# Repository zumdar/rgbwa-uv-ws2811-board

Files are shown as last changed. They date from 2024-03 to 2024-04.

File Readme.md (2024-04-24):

# RGBWA+UV LED with 2x WS2811 chipss

fun collab w/ eddie farr!

Eddie made CamperLightsSMD and I modified and made the dome_rgbwauv_pcb file

# dome_rgbwauv_pcb

For the LED dome / barnacle project
Rev. A:
- features mosfet circuit so more current can go to the led
- jumper so you can toggle between the mosfet circuit and just using the ws2811 output
- 2x holes (H1 & H2) should line up so you can screw this pcb into the plastic dome and use it as base
- JST connector on back so you can connect data and power easily
- 4 other holes to mount standoffs so you can mount this on a substrate?
- hole in middle of LED for heatsink

# similar projects
Neopixel XL - https://github.com/palsayantan/Neopixel-XL

## REV. A renders
front:
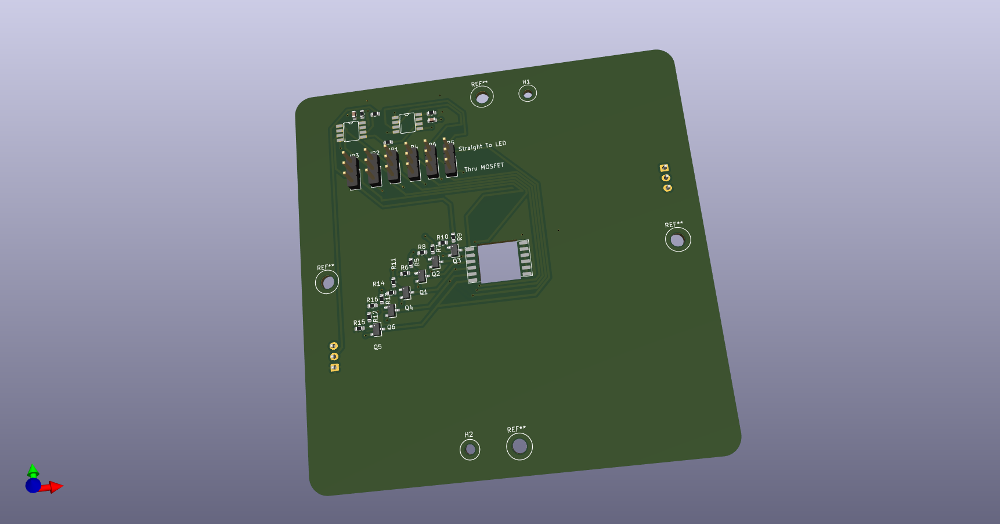
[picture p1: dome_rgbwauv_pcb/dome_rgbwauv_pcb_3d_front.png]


back:
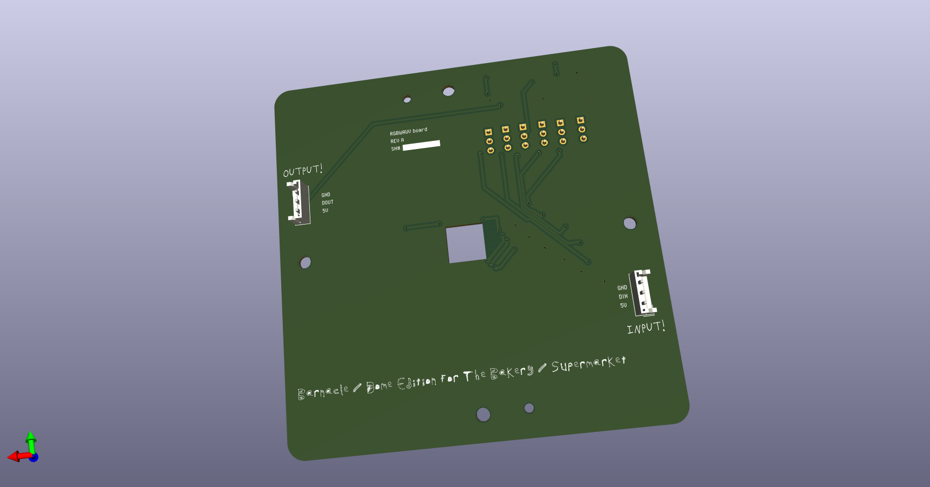
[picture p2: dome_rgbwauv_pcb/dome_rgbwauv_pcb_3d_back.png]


[Rev A Layout PDF](dome_rgbwauv_pcb/dome_rgbwauv_pcb_LAYOUT.pdf)
## Schematic 
[Schematic](dome_rgbwauv_pcb/dome_rgbwauv_Schematic.pdf)

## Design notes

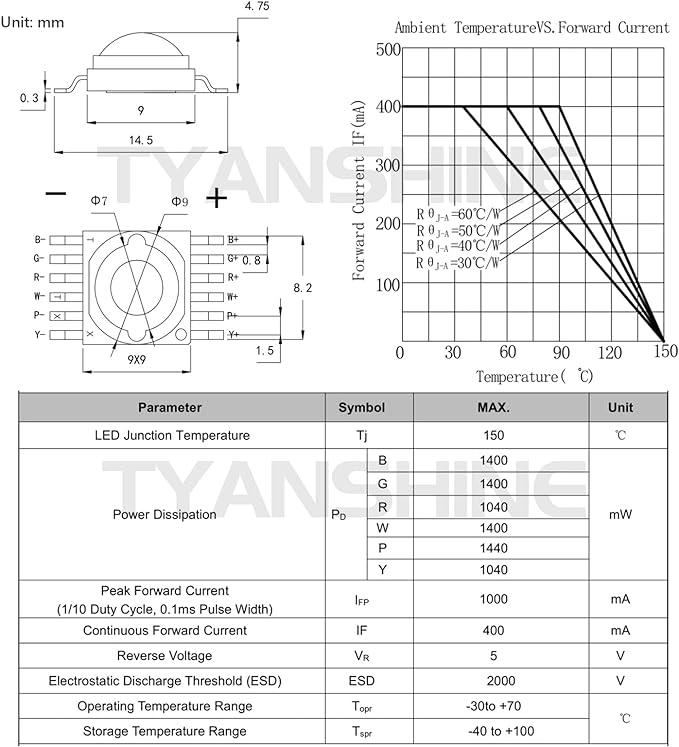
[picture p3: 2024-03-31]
Datasheets/led_data_sheet1.jpg

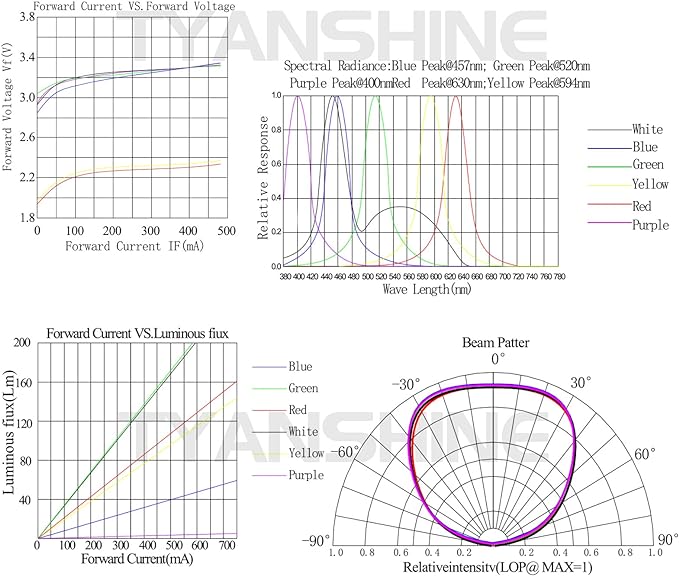
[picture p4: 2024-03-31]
Datasheets/led_data_sheet2.jpg

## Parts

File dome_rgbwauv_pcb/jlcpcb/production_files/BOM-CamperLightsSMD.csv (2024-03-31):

Comment | Designator | Footprint | LCSC
0.1 uf | C1,C2 | C_0603_1608Metric | C14663
100 | R2,R4 | R_0603_1608Metric | C22775
33 | R1,R3 | R_0603_1608Metric | C23140
WS2811 | IC1,IC2 | SO08-SKINNYPADS | C2920043
RGBAW+UV | U1 | RGBWA+UV
MountingHole | H2 | MountingHole_2.2mm_M2
MountingHole | H1 | MountingHole_2.2mm_M2
Conn_01x03_Male | J2 | JST_EH_B3B-EH-A_1x03_P2.50mm_Vertical
Conn_01x03_Male | J1 | JST_EH_B3B-EH-A_1x03_P2.50mm_Vertical

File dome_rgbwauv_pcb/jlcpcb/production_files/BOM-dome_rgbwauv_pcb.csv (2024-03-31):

Comment | Designator | Footprint | LCSC
0.1 uf | C1,C2 | C_0603_1608Metric | C14663
AO3400A | Q1,Q2,Q3,Q4,Q5,Q6 | SOT-23-3_L2.9-W1.6-P1.90-LS2.8-BR | C20917
1k | R11,R12,R13,R5,R7,R9 | R_0603_1608Metric | C21190
100 | R2,R4 | R_0603_1608Metric | C22775
33 | R1,R3 | R_0603_1608Metric | C23140
10k | R10,R14,R15,R16,R6,R8 | R_0603_1608Metric | C25804
WS2811 | IC1,IC2 | SO08-SKINNYPADS | C2920043
RGBAW+UV | U1 | RGBWA+UV
Board_to_dome | H2 | MountingHole_2.2mm_M2
Board_to_dome | H1 | MountingHole_2.2mm_M2
3PinJSTOutput | J2 | JST_EH_B3B-EH-A_1x03_P2.50mm_Vertical
3PinJSTInput | J1 | JST_EH_B3B-EH-A_1x03_P2.50mm_Vertical
Jumper | JP1 | PinHeader_1x03_P2.54mm_Vertical
Jumper | JP2 | PinHeader_1x03_P2.54mm_Vertical
Jumper | JP5 | PinHeader_1x03_P2.54mm_Vertical
Jumper | JP3 | PinHeader_1x03_P2.54mm_Vertical
Jumper | JP4 | PinHeader_1x03_P2.54mm_Vertical
Jumper | JP6 | PinHeader_1x03_P2.54mm_Vertical

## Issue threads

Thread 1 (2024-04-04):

improvement of REV.A pcb run

zumdar, 2024-04-04:
Potential upgrades or problems with board
- 12V input might be better then 5V
   - would need a 12 to 5 regulator for the chip
- heat sink the whole board?

zumdar, 2024-04-10:
- mosfet needs to be pulled high .? when not actively driven...

zumdar, 2024-05-09:
- it is being pulled high when not driven. so need to get multimeter or scope out and read voltage on it.

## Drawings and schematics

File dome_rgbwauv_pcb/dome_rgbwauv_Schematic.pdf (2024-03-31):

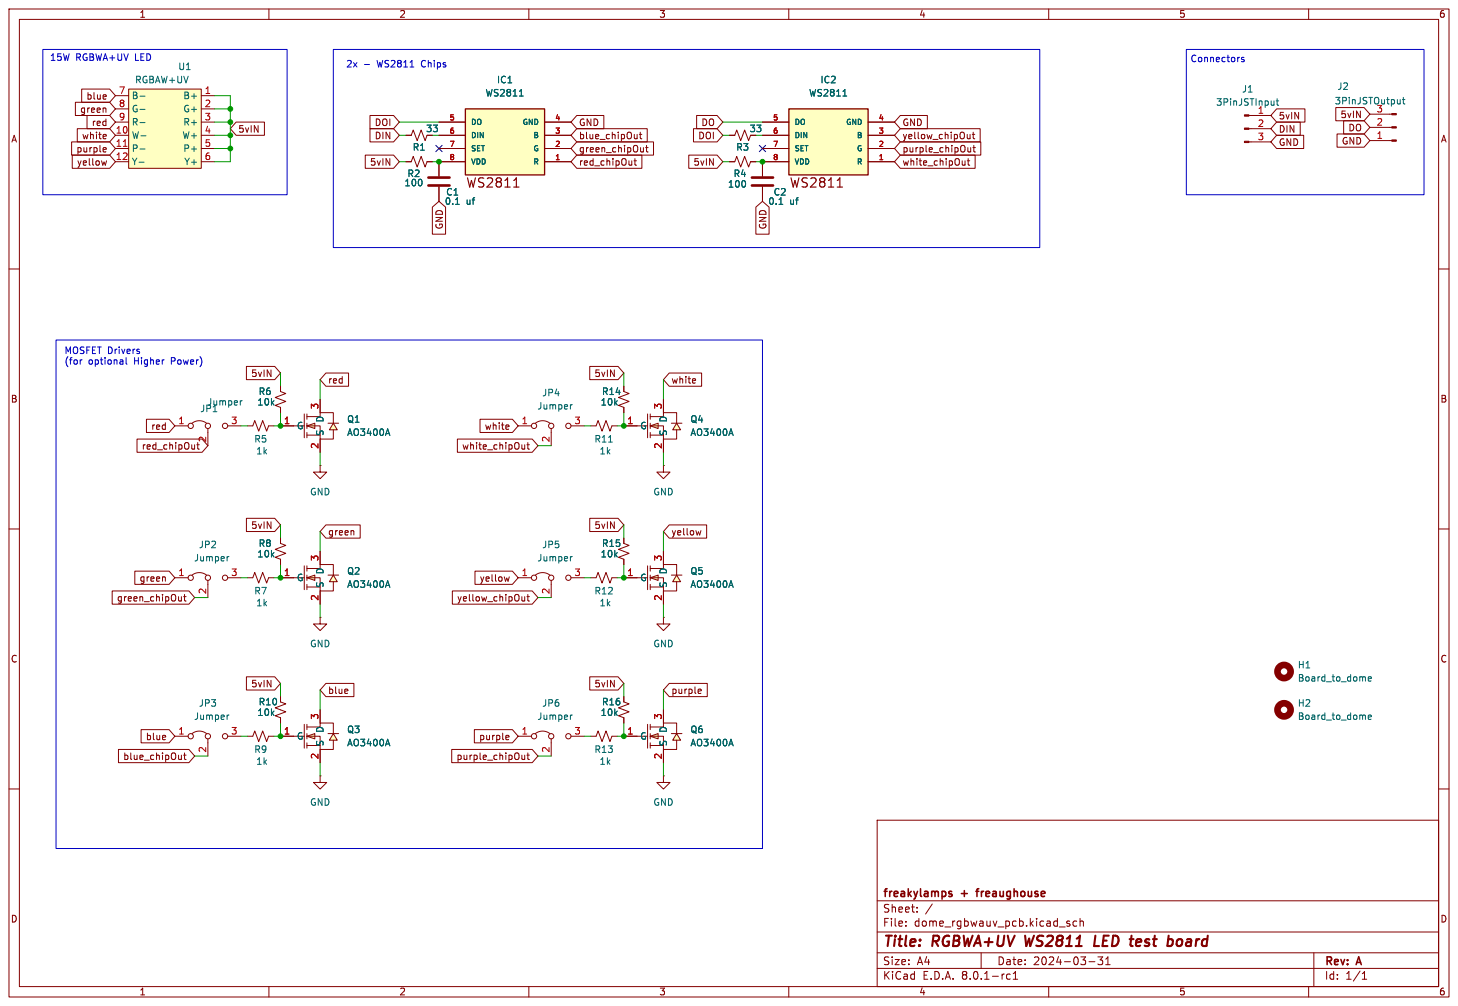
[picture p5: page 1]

Id: 1/1 Title: RGBWA+UV WS2811 LED test board

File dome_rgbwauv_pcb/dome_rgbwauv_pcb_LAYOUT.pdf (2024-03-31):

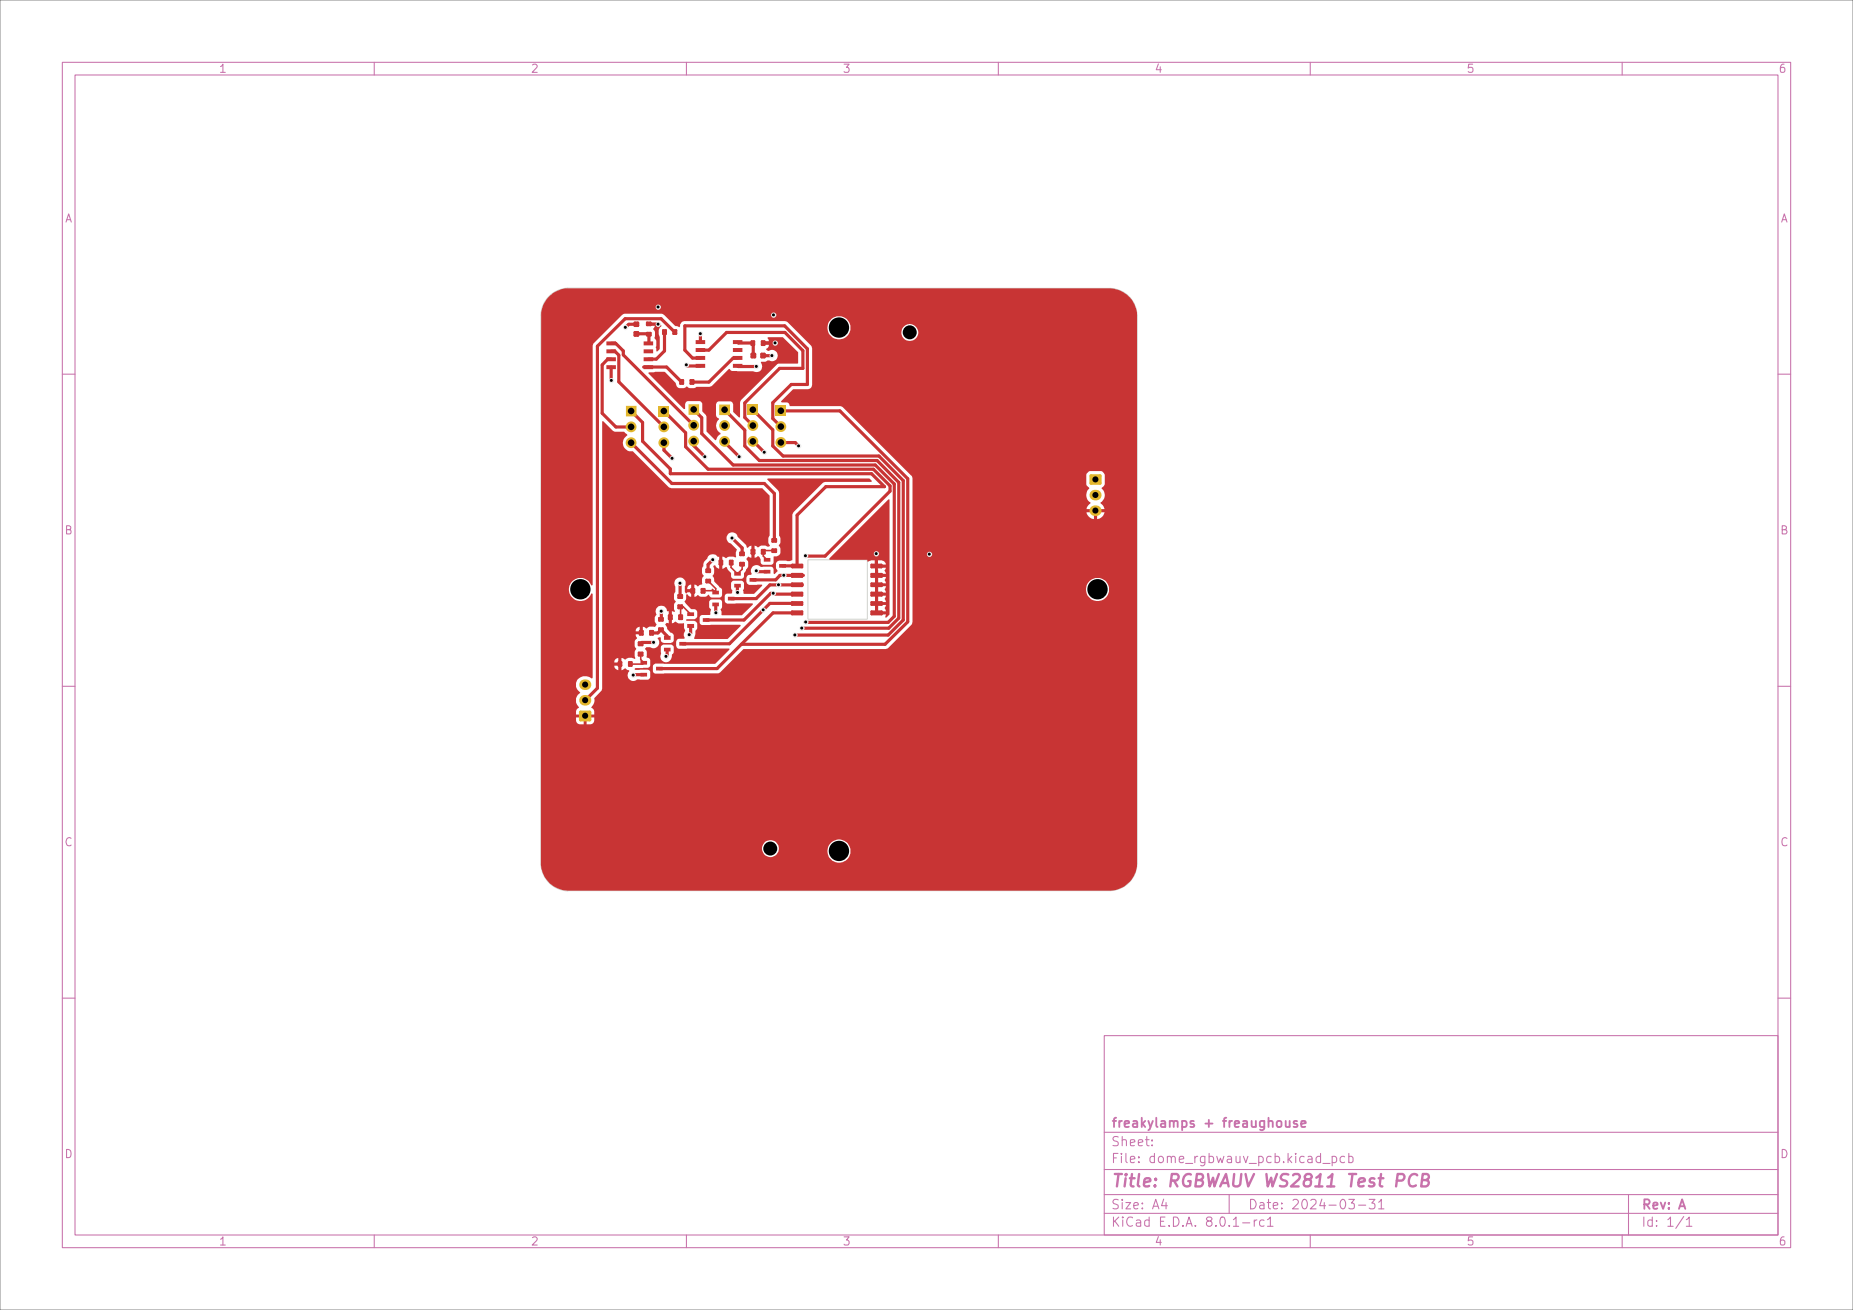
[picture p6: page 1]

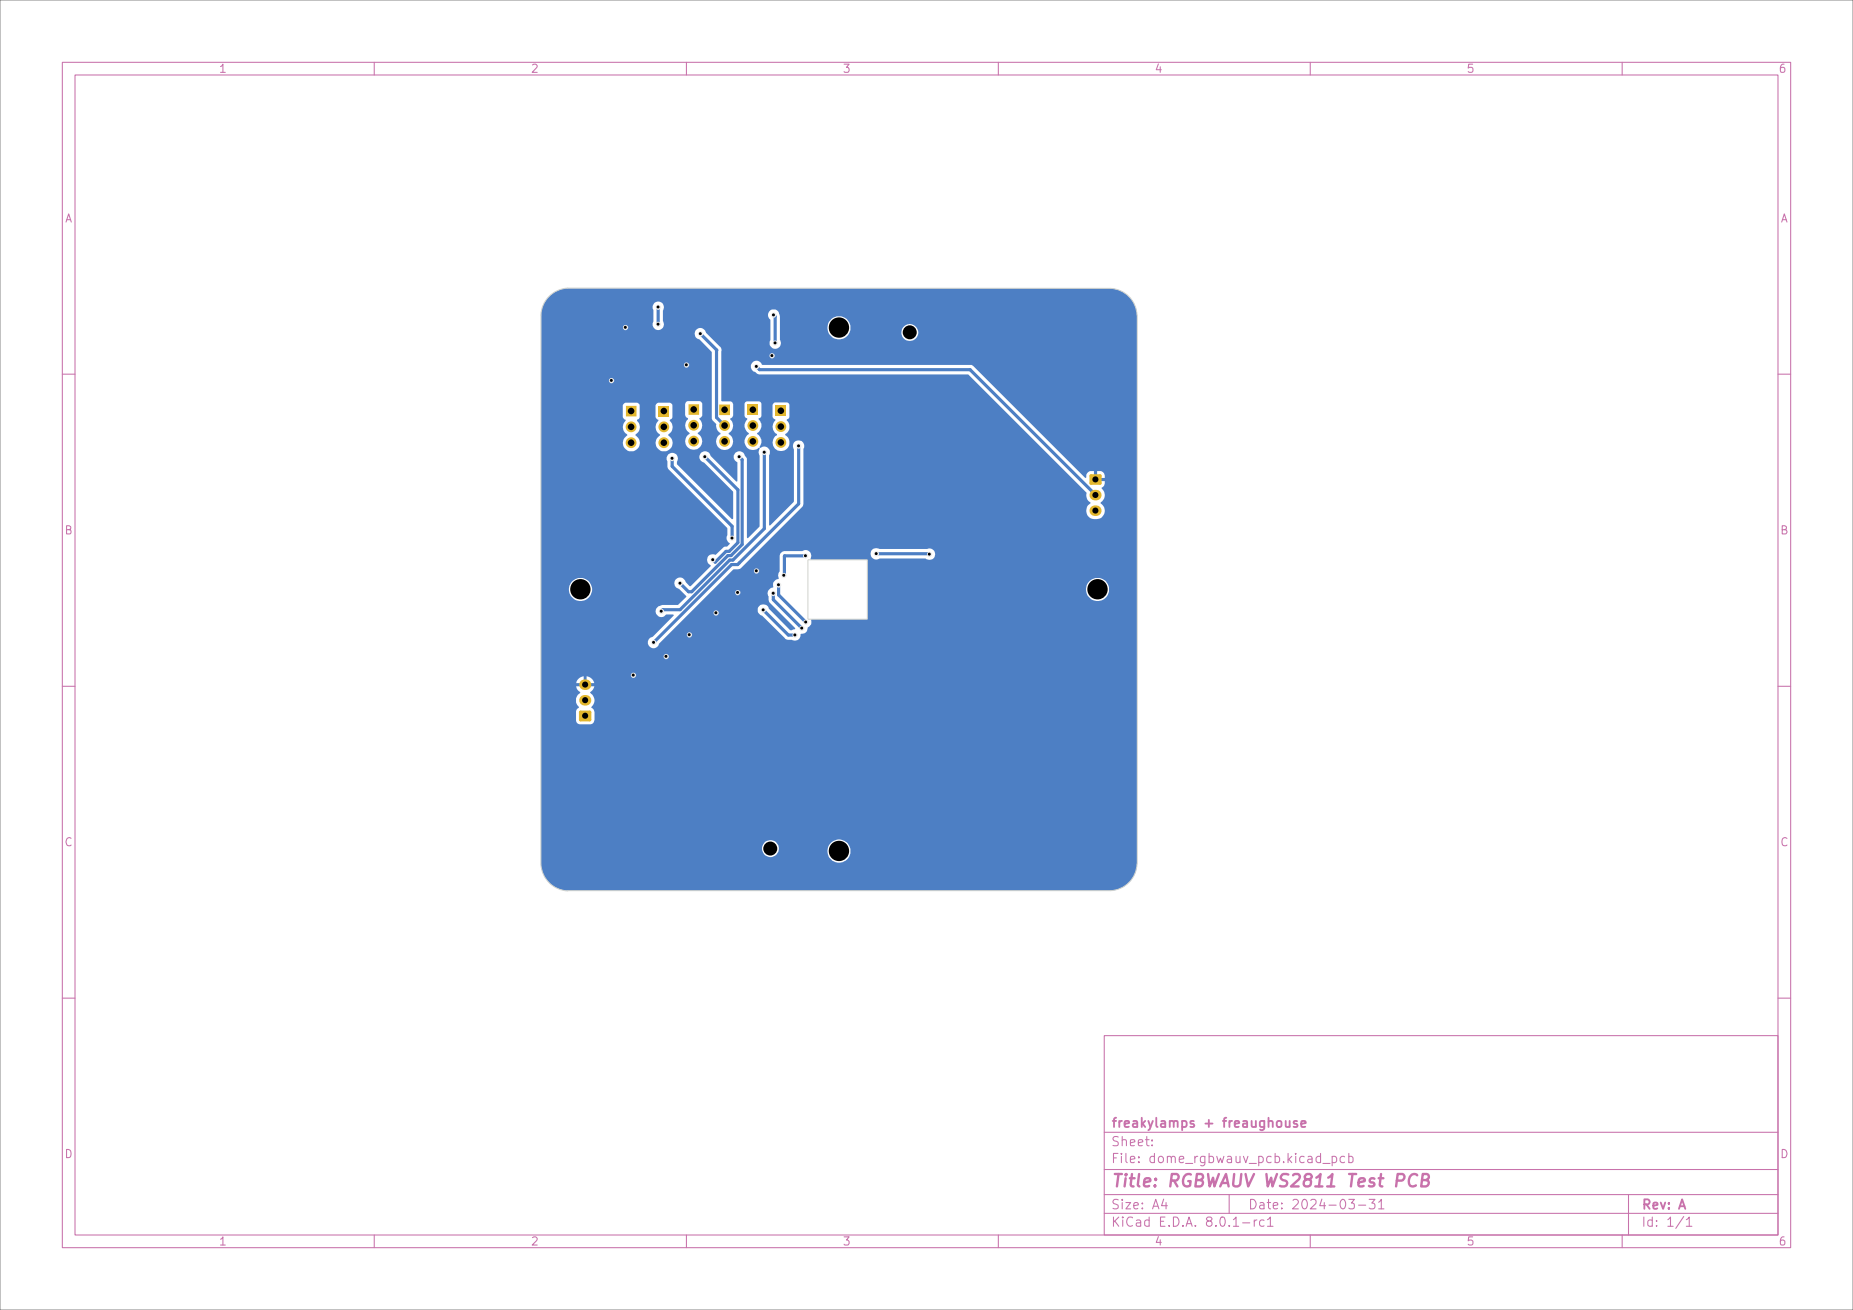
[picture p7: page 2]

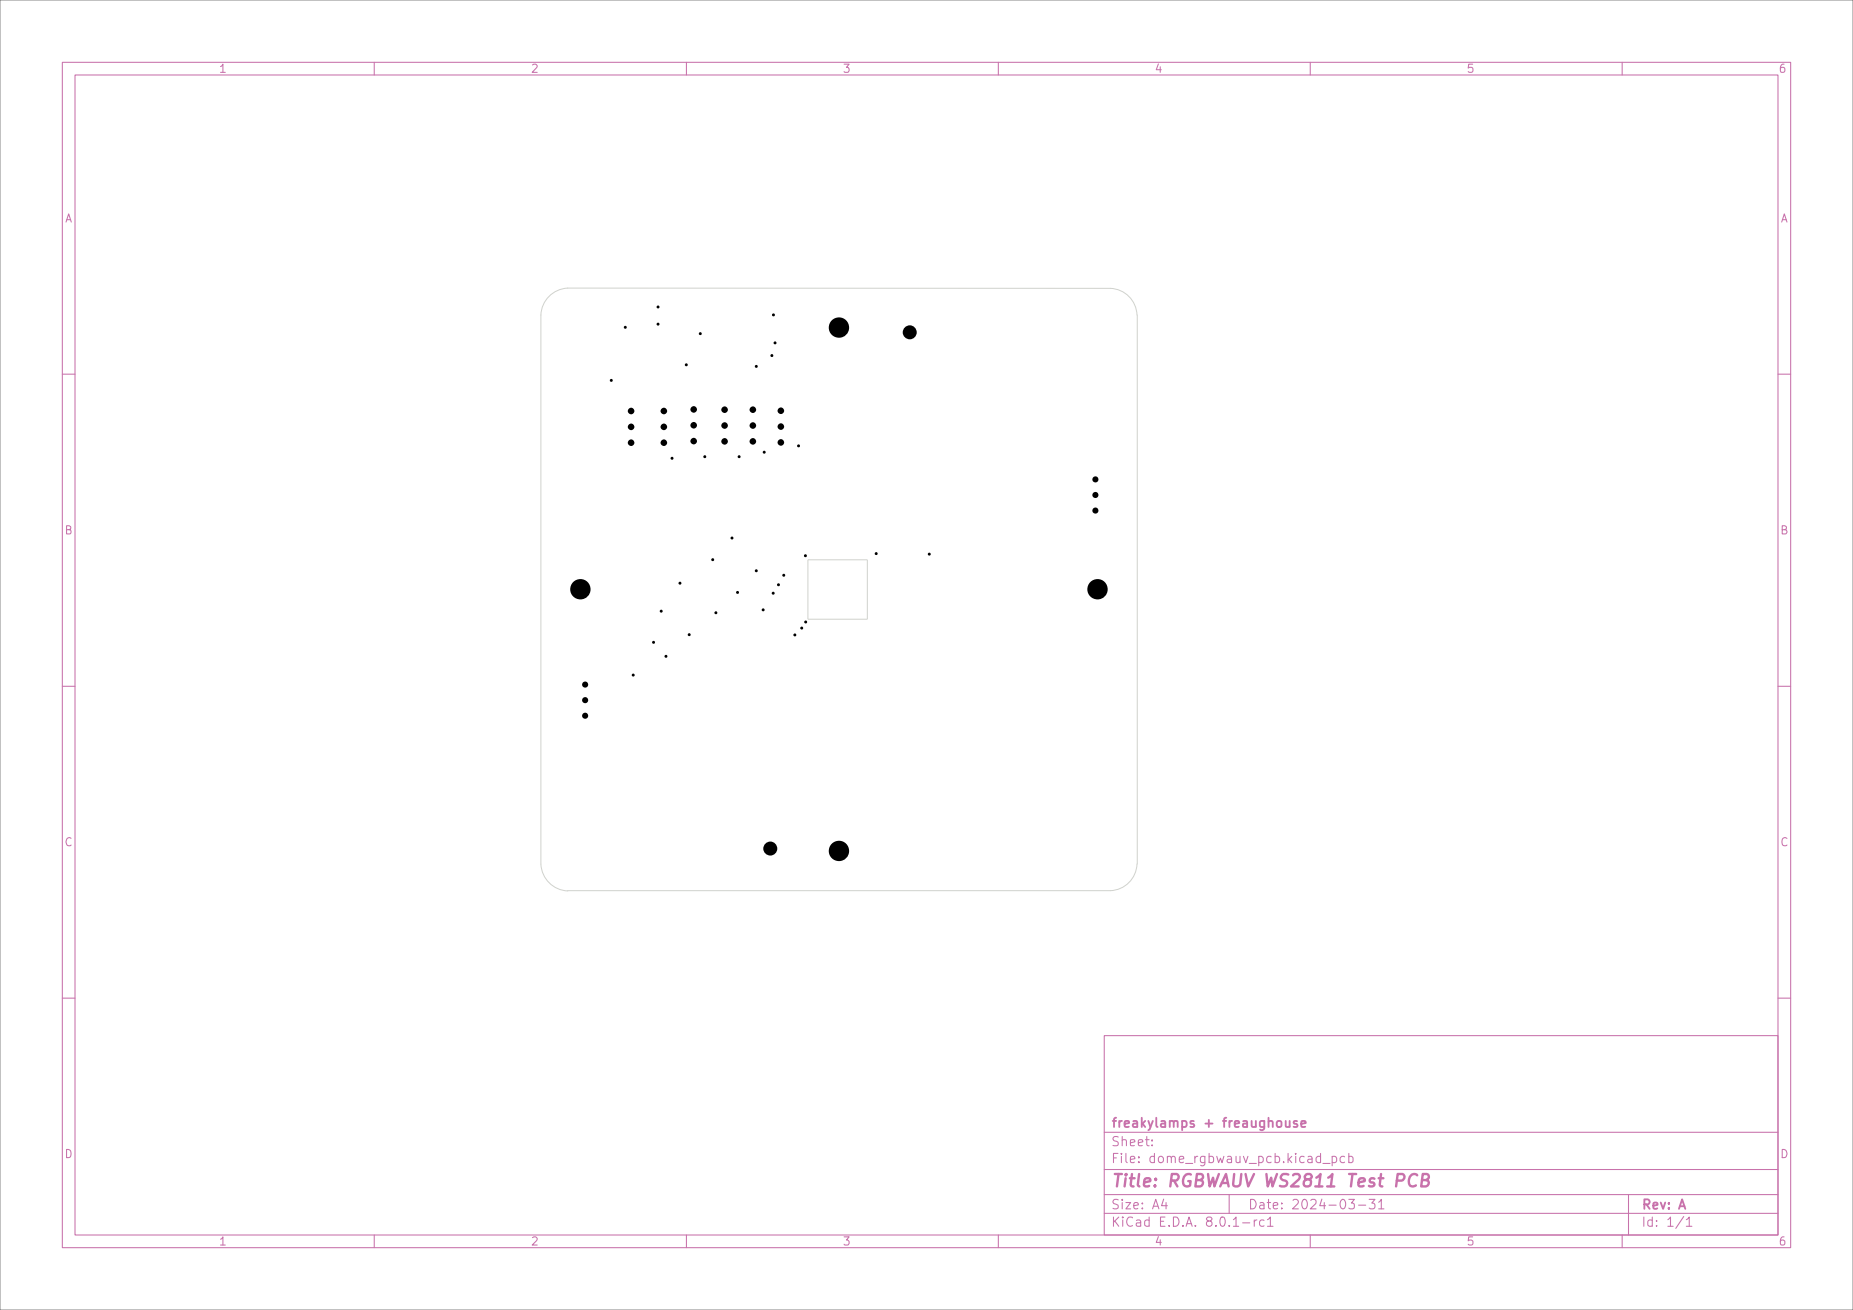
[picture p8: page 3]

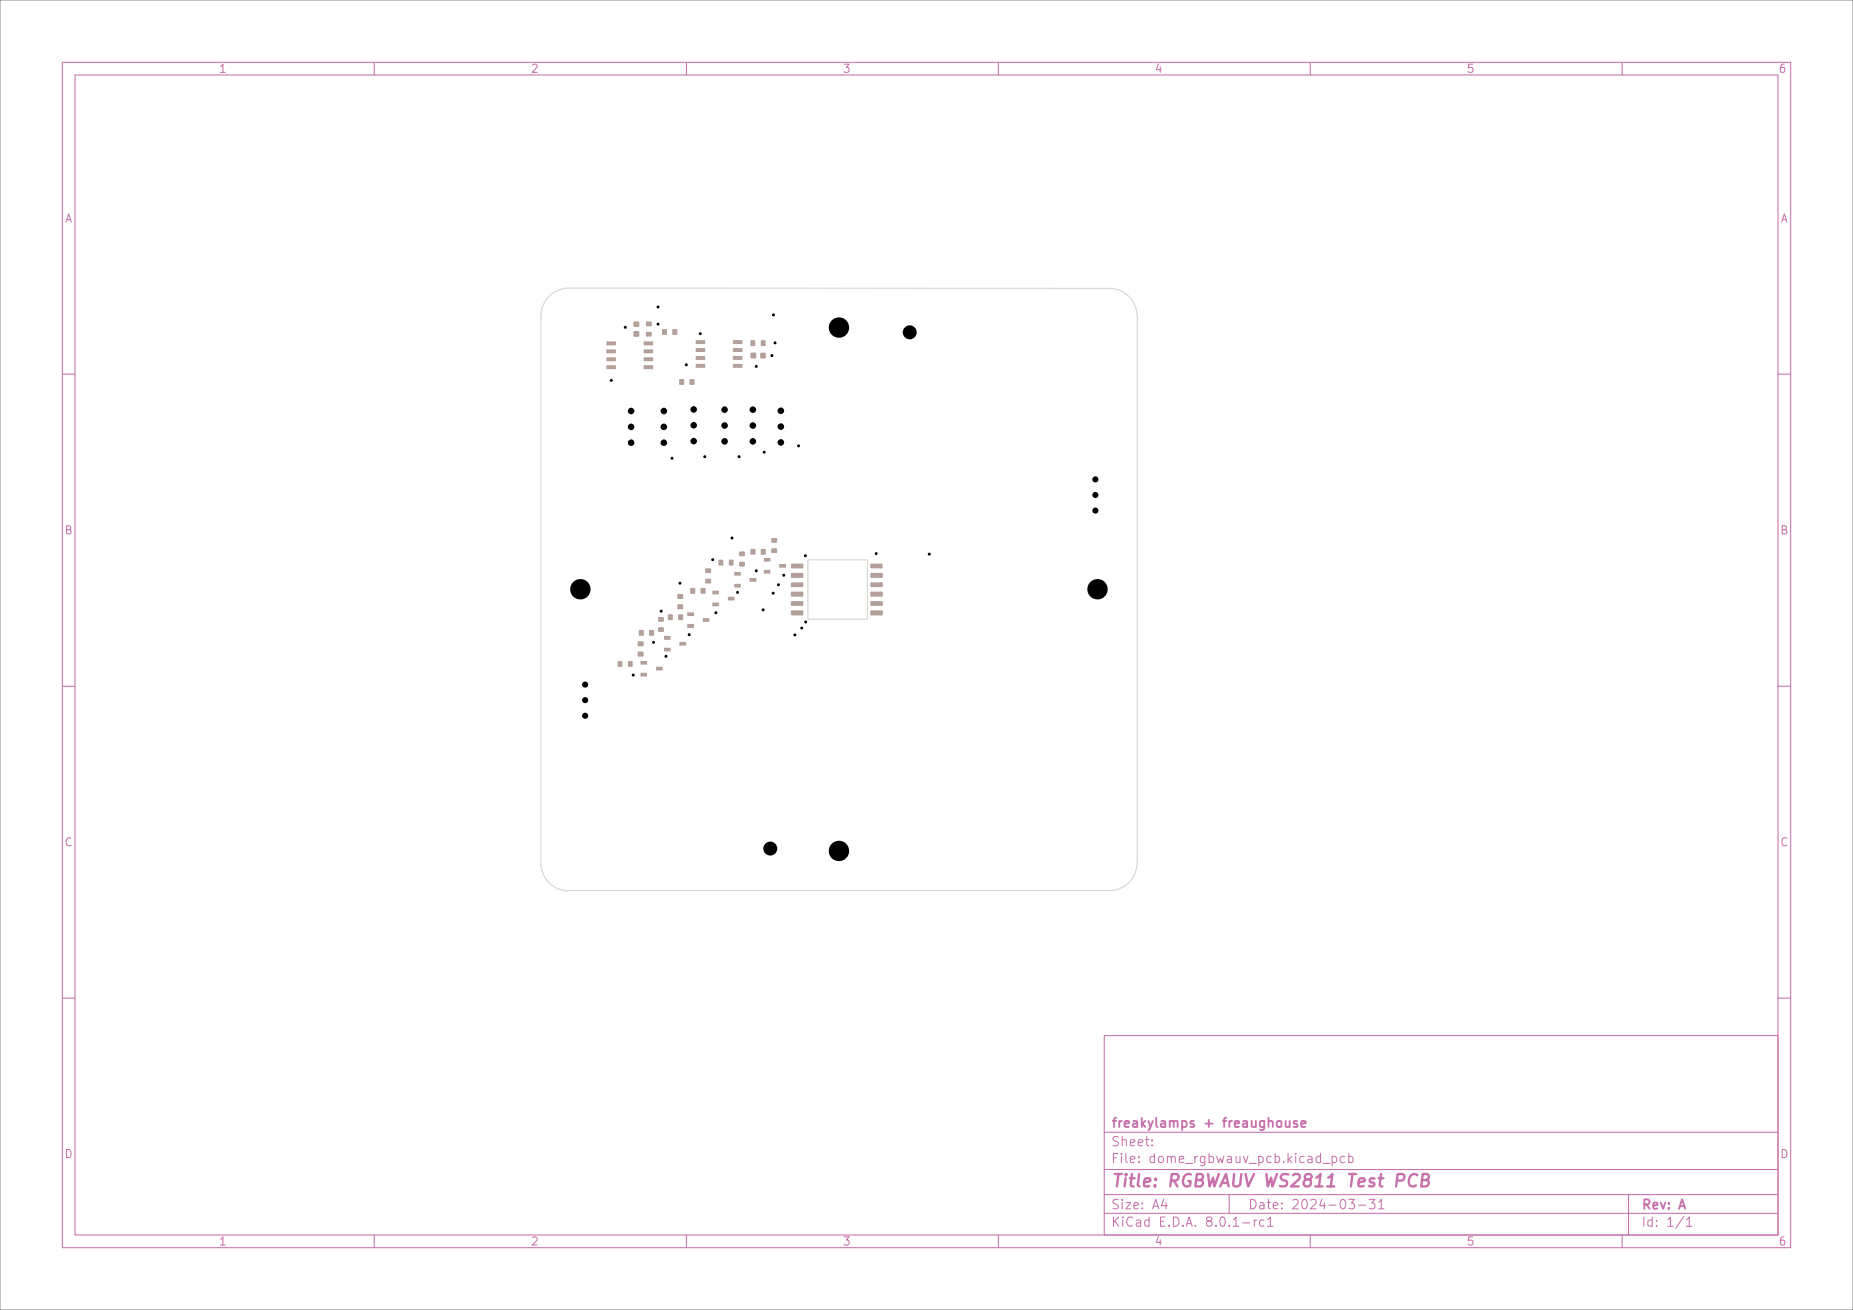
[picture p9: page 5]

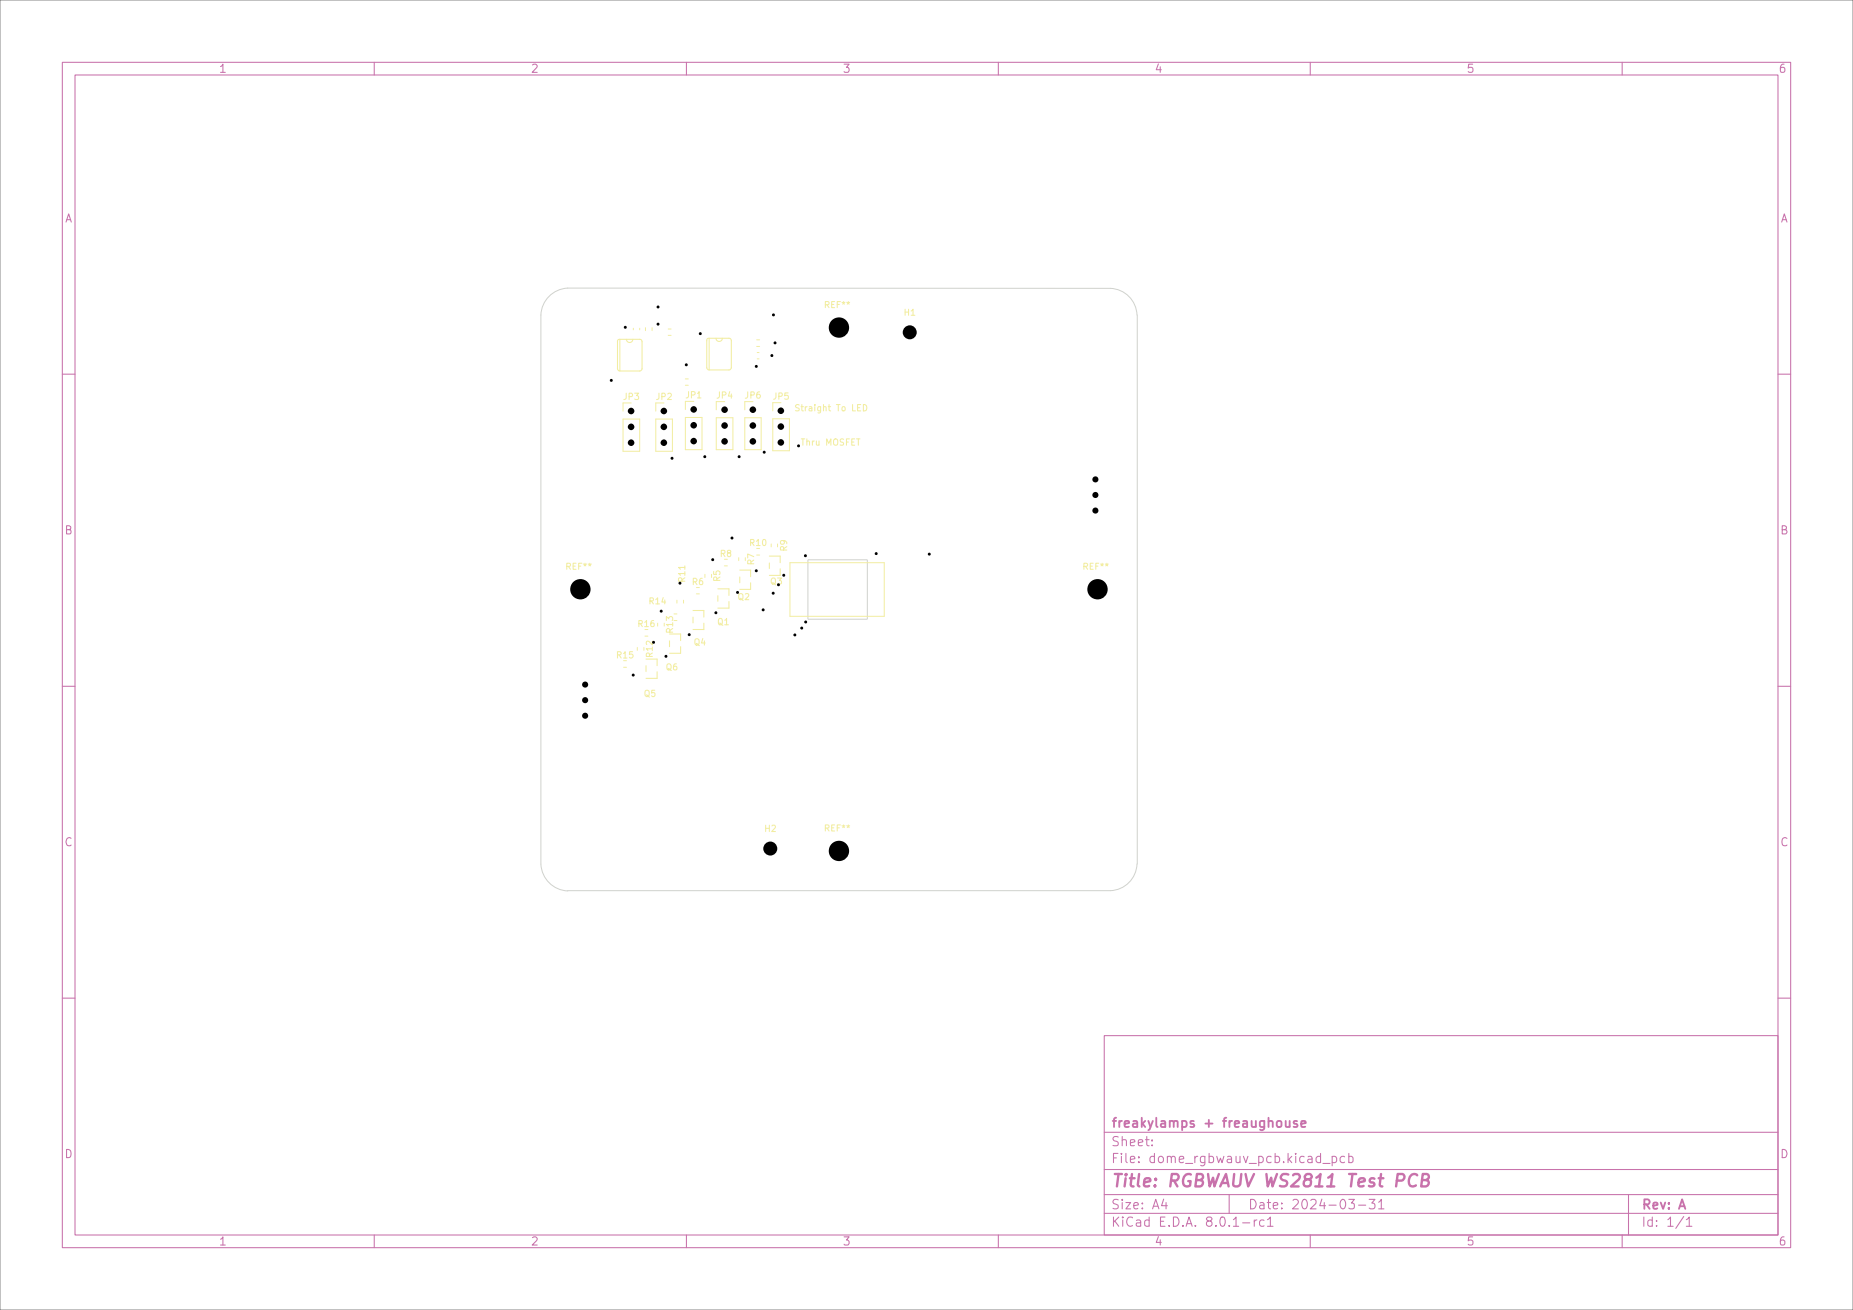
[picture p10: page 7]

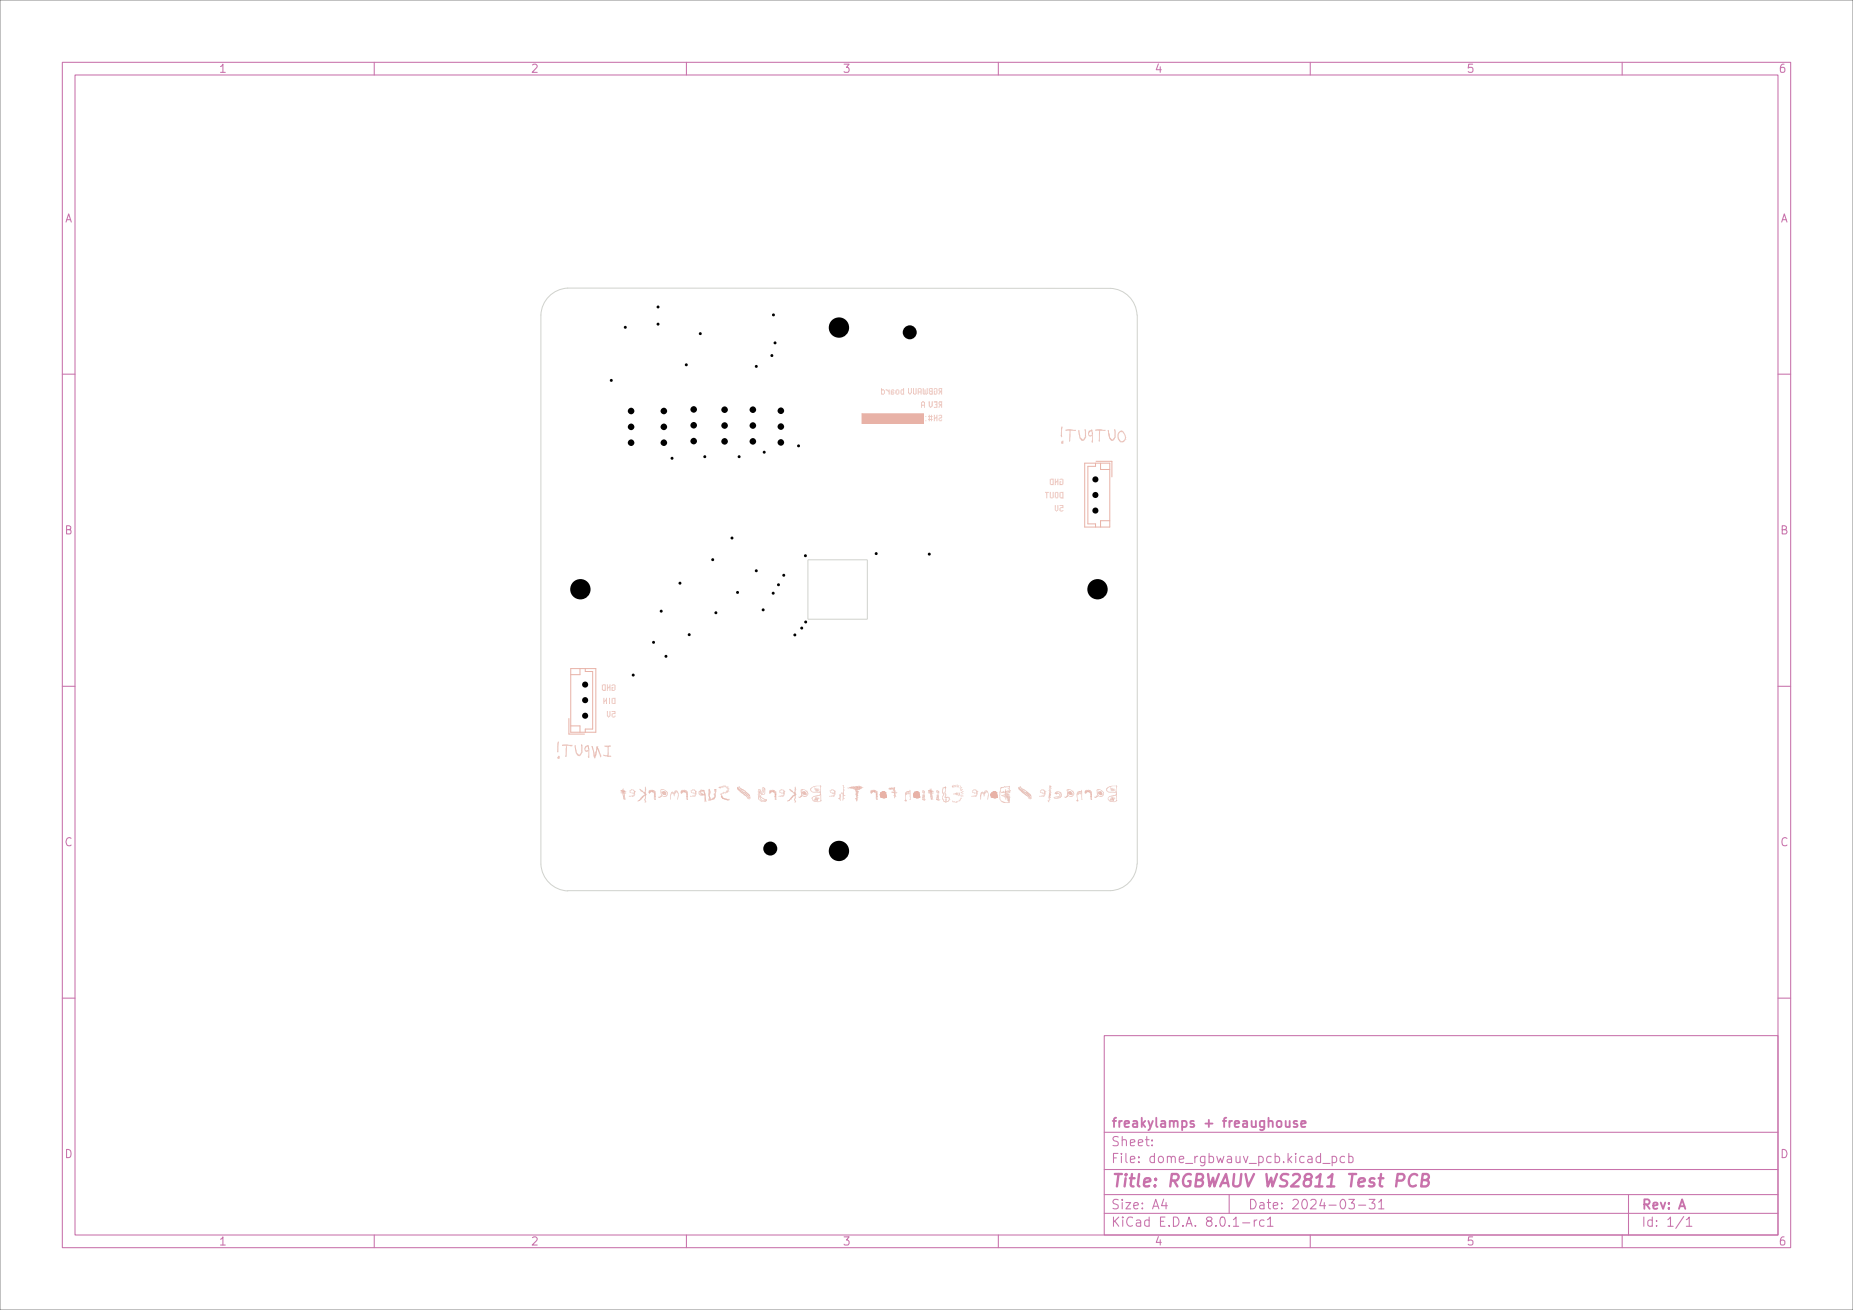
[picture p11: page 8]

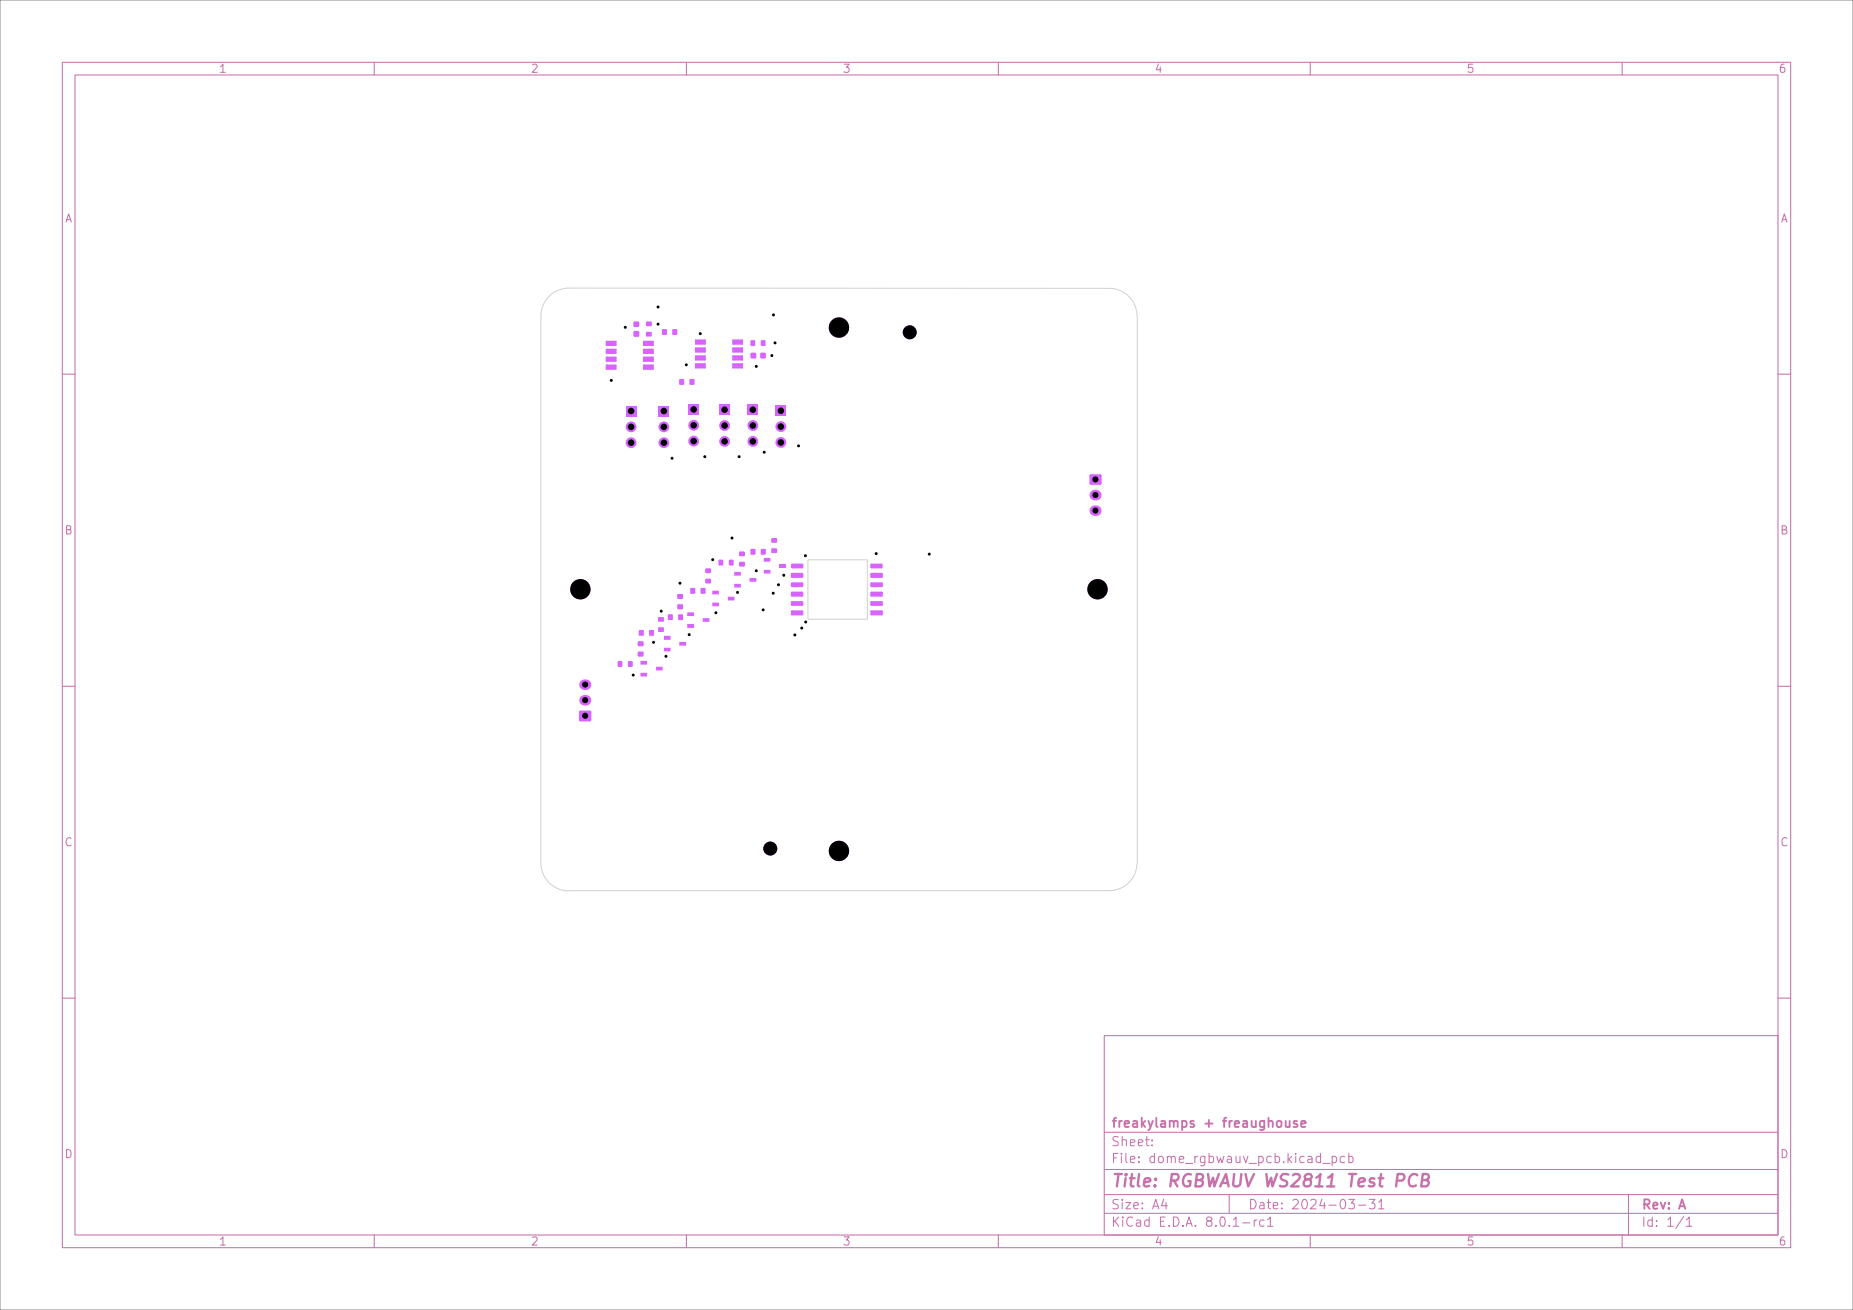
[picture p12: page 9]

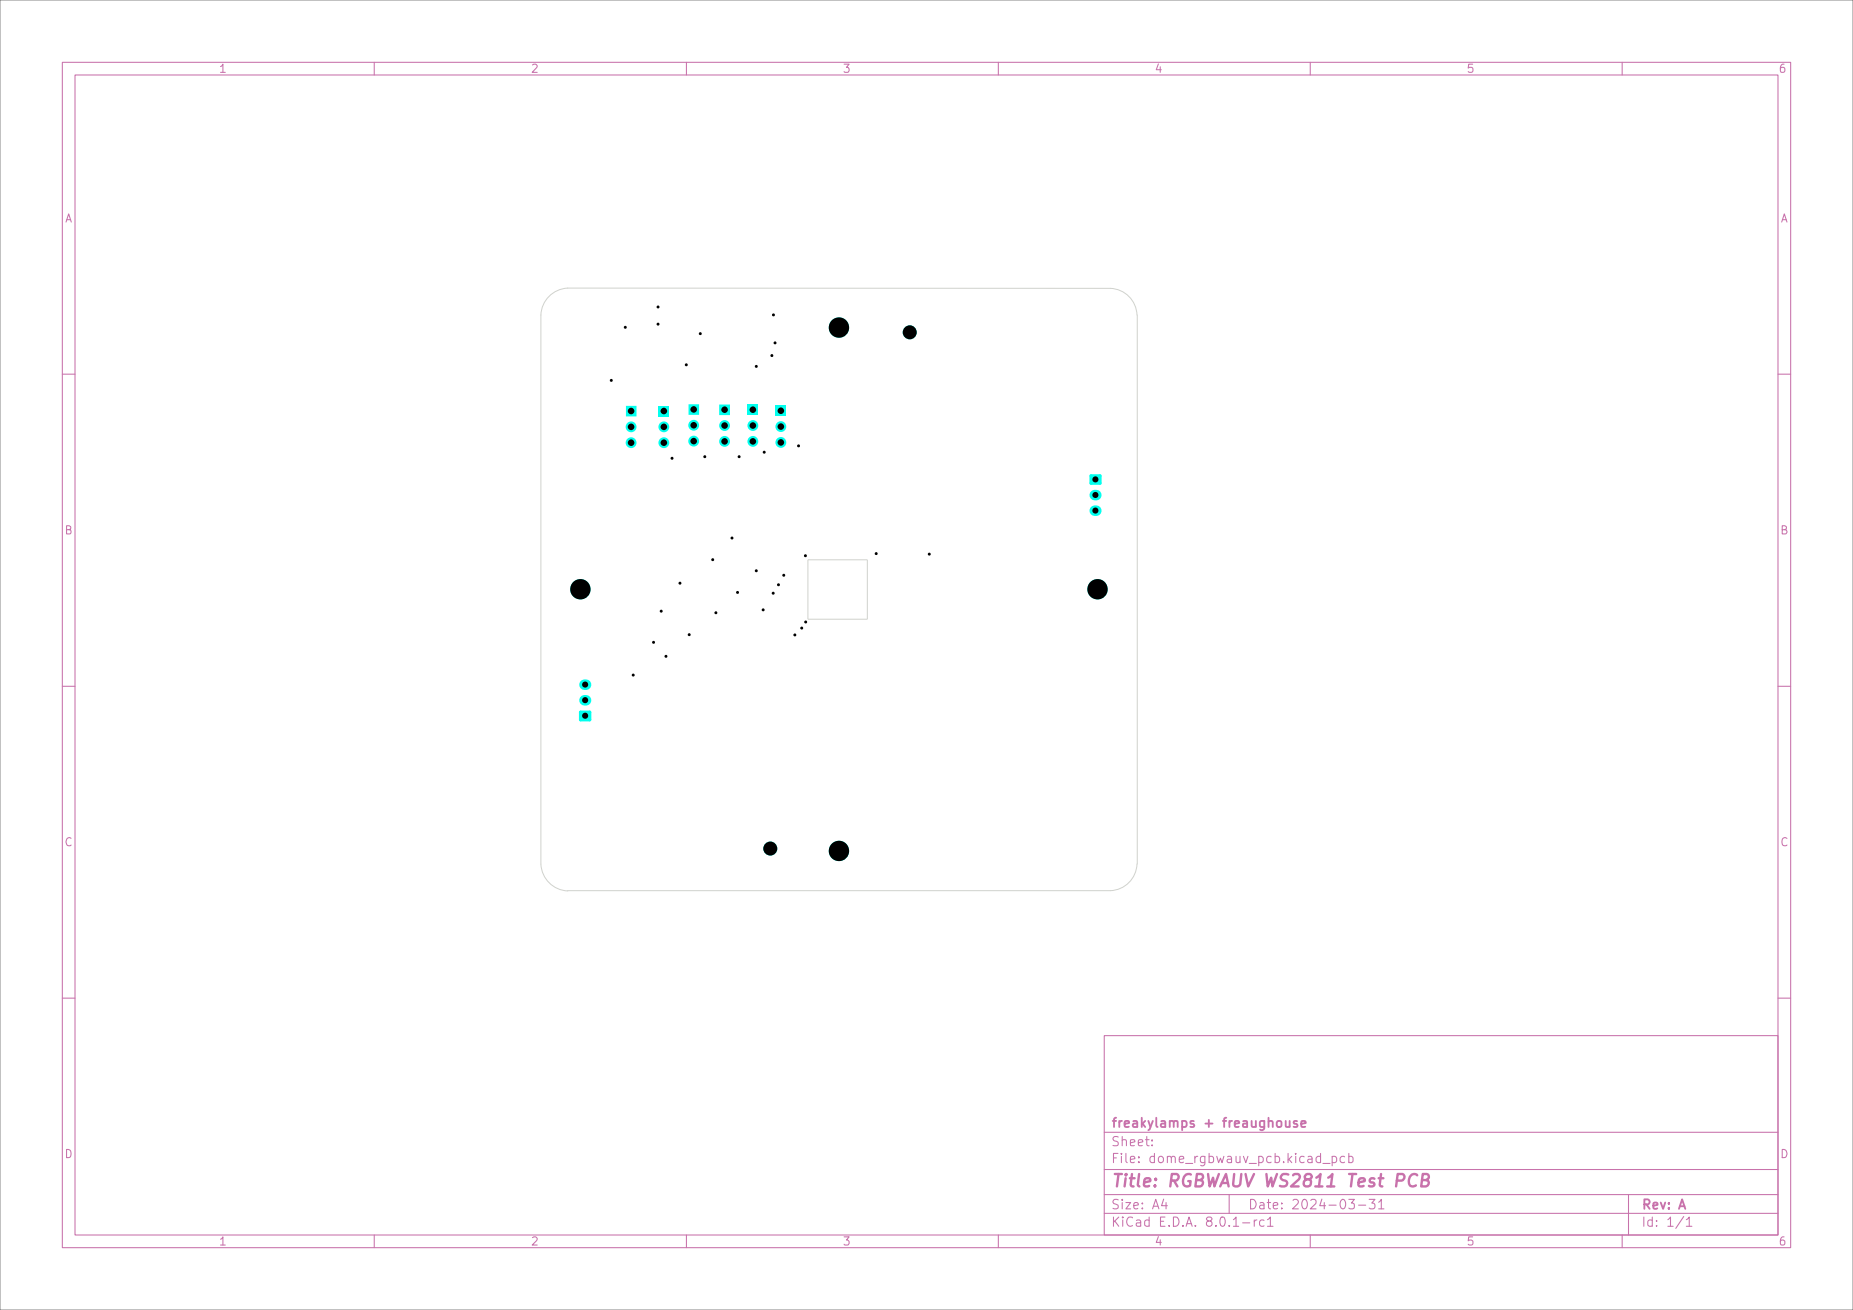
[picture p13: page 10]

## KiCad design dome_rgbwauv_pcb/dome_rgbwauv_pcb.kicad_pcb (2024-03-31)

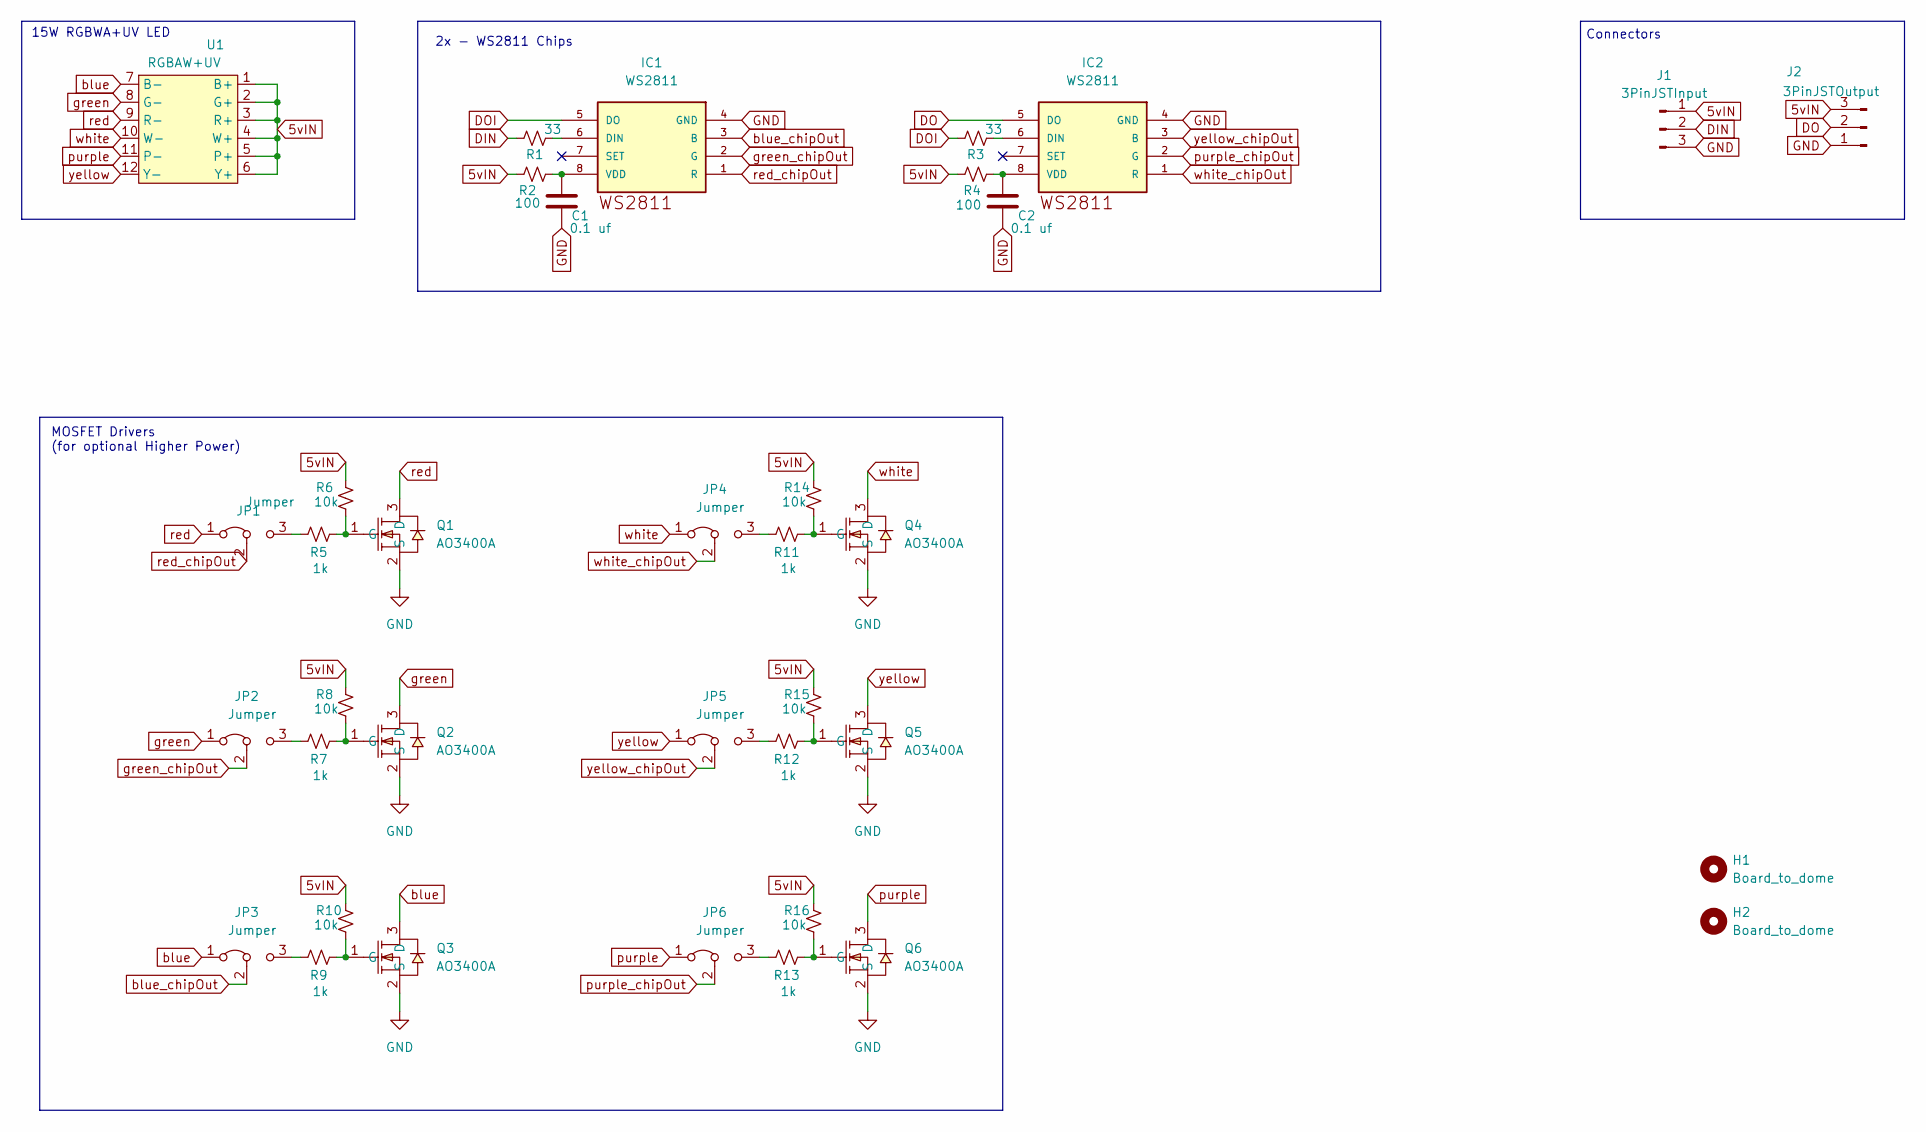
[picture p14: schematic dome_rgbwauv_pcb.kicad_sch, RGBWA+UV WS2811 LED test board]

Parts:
C1, C2: 0.1 uf; C_0603_1608Metric
H1, H2: Board_to_dome; MountingHole_2.2mm_M2
IC1, IC2: WS2811; SO08-SKINNYPADS
J1: 3PinJSTInput; JST_EH_B3B-EH-A_1x03_P2.50mm_Vertical
J2: 3PinJSTOutput; JST_EH_B3B-EH-A_1x03_P2.50mm_Vertical
JP1, JP2, JP3, JP4, JP5, JP6: Jumper; PinHeader_1x03_P2.54mm_Vertical
Q1, Q2, Q3, Q4, Q5, Q6: AO3400A; SOT-23-3_L2.9-W1.6-P1.90-LS2.8-BR; LCSC Part C20917
R1, R3: 33; R_0603_1608Metric
R2, R4: 100; R_0603_1608Metric
R5, R7, R9, R11, R12, R13: 1k; R_0603_1608Metric
R6, R8, R10, R14, R15, R16: 10k; R_0603_1608Metric
U1: RGBAW+UV; RGBWA+UV

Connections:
5vIN: J1.1, J2.3, R2.1, R4.1, R6.1, R8.1, R10.1, R14.1, R15.1, R16.1, U1.1 (B+), U1.2 (G+), U1.3 (R+), U1.4 (W+), U1.5 (P+), U1.6 (Y+)
DIN: J1.2, R1.1
DO: IC2.5 (DO), J2.2
DOI: IC1.5 (DO), R3.1
GND: C1.2, C2.2, IC1.4 (GND), IC2.4 (GND), J1.3, J2.1, Q1.2 (S), Q2.2 (S), Q3.2 (S), Q4.2 (S), Q5.2 (S), Q6.2 (S)
unnamed: IC1.6 (DIN), R1.2
unnamed: C1.1, IC1.8 (VDD), R2.2
unnamed: IC2.6 (DIN), R3.2
unnamed: C2.1, IC2.8 (VDD), R4.2
unnamed: JP1.3 (B), R5.1
unnamed: JP2.3 (B), R7.1
unnamed: JP3.3 (B), R9.1
unnamed: JP4.3 (B), R11.1
unnamed: JP5.3 (B), R12.1
unnamed: JP6.3 (B), R13.1
unnamed: Q1.1 (G), R5.2, R6.2
unnamed: Q2.1 (G), R7.2, R8.2
unnamed: Q3.1 (G), R9.2, R10.2
unnamed: Q4.1 (G), R11.2, R14.2
unnamed: Q5.1 (G), R12.2, R15.2
unnamed: Q6.1 (G), R13.2, R16.2
blue: JP3.1 (A), Q3.3 (D), U1.7 (B-)
blue_chipOut: IC1.3 (B), JP3.2 (C)
green: JP2.1 (A), Q2.3 (D), U1.8 (G-)
green_chipOut: IC1.2 (G), JP2.2 (C)
purple: JP6.1 (A), Q6.3 (D), U1.11 (P-)
purple_chipOut: IC2.2 (G), JP6.2 (C)
red: JP1.1 (A), Q1.3 (D), U1.9 (R-)
red_chipOut: IC1.1 (R), JP1.2 (C)
white: JP4.1 (A), Q4.3 (D), U1.10 (W-)
white_chipOut: IC2.1 (R), JP4.2 (C)
yellow: JP5.1 (A), Q5.3 (D), U1.12 (Y-)
yellow_chipOut: IC2.3 (B), JP5.2 (C)

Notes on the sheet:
15W RGBWA+UV LED
Connectors
MOSFET Drivers (for optional Higher Power)
2x - WS2811 Chips

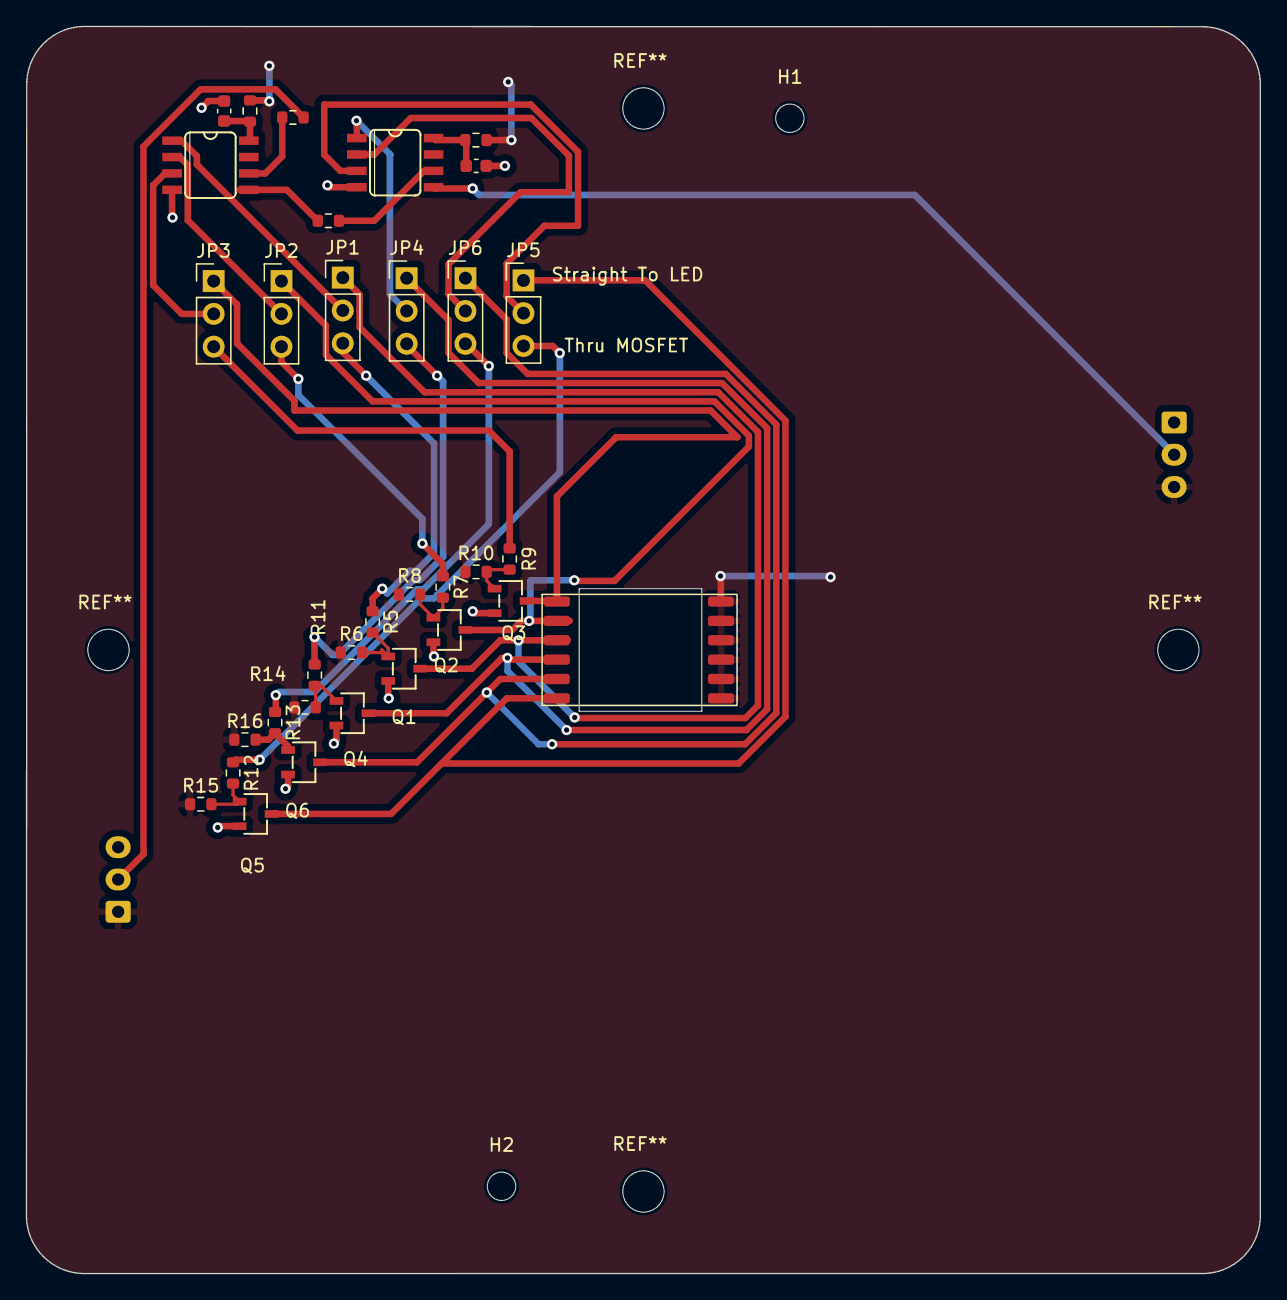
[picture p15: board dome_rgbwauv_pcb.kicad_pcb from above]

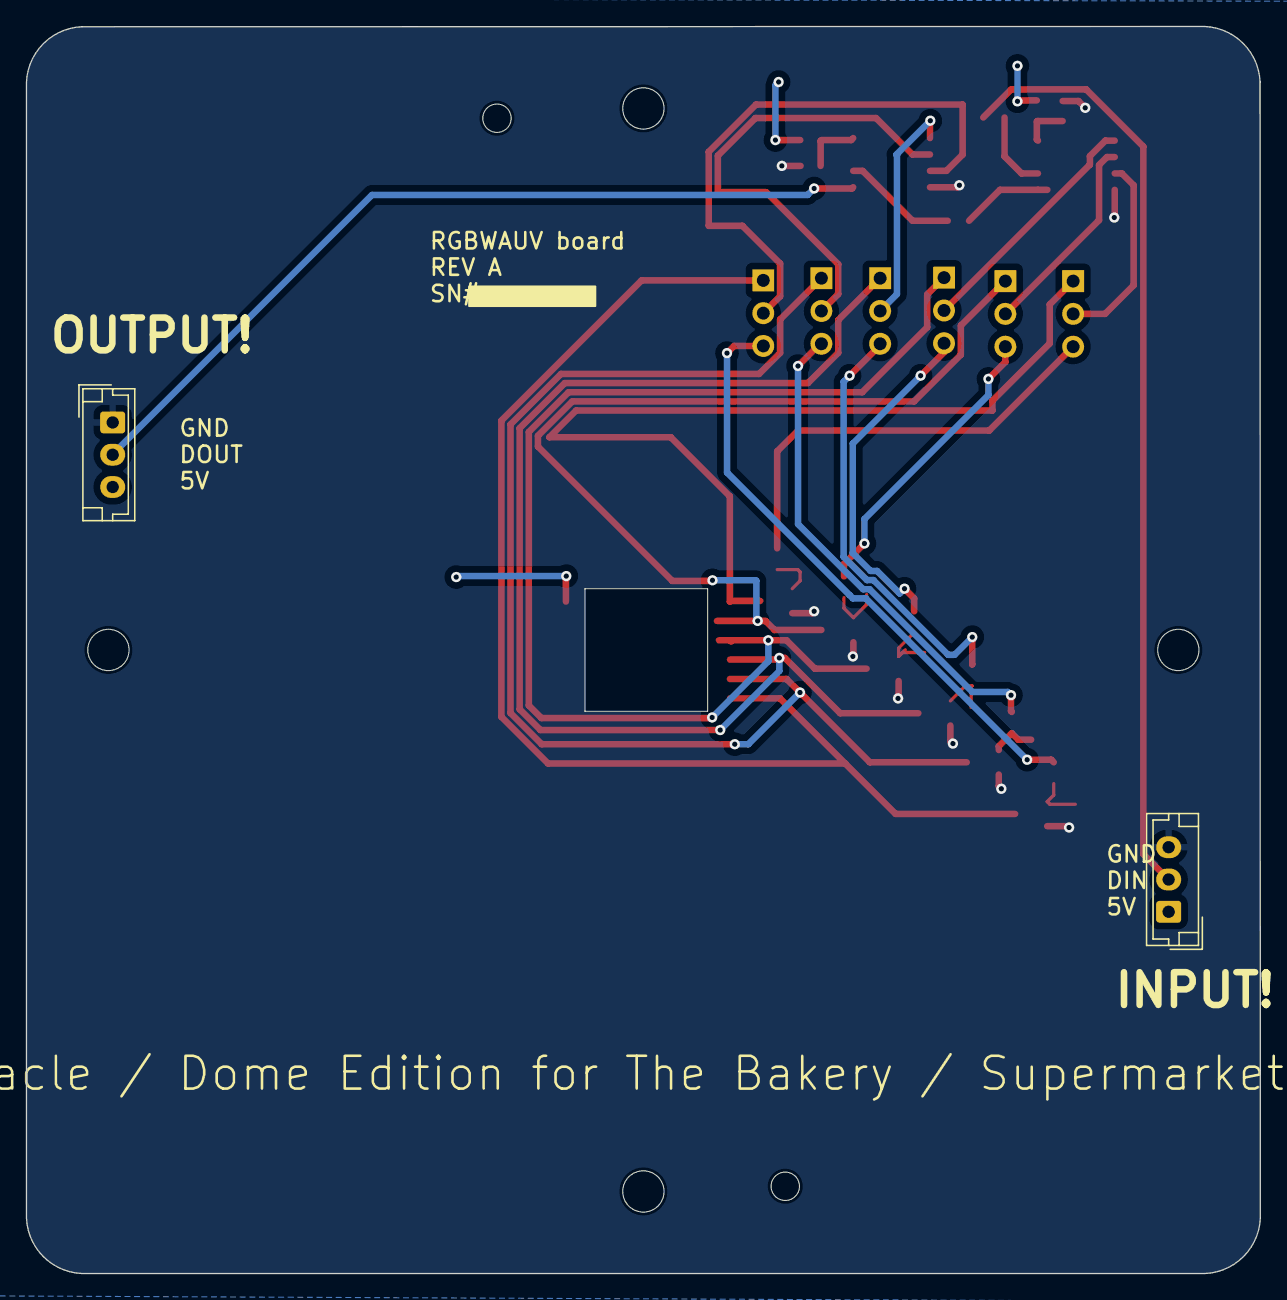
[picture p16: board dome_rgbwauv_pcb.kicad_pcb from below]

Board: 2 copper layers, 95.6 x 96.6 mm, 37 parts (2 on the bottom side), 33 nets.

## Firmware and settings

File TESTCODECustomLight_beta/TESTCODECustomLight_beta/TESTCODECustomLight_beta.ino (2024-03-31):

#include <FastLED.h>

// How many leds in your strip?
#define NUM_LEDS 2

#define DATA_PIN 4

// Define the array of leds
CRGB leds[NUM_LEDS];

void setup() {
  FastLED.addLeds<WS2811, DATA_PIN, RGB>(leds, NUM_LEDS);
}

void loop() {
  // Turn the LED on, then pause
  leds[0].r = 0; //r
  leds[0].g = 0;  //g
  leds[0].b = 0;   //b
  leds[1].r = 0; //w
  leds[1].g = 0; //p
  leds[1].b = 255; //amber
  leds[2].r = 0; //r
  leds[2].g = 0;  //g
  leds[2].b = 0;   //b
  leds[3].r = 0; //w
  leds[3].g = 0; //p
  leds[3].b = 255; //amber

  FastLED.show();
}

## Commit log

2024-03-31 adding readme and nicer pdf
    [dome_rgbwauv_pcb.kicad_pcb]
2024-04-04 Add files via upload
    adding led data sheet eddie emailed me
